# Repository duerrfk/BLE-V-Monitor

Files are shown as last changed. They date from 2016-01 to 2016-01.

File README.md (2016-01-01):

BLE-V-Monitor is a battery voltage monitor for vehicles (cars, motorbikes). It consists of an Arduino-based monitoring device and an Android app. The BLE-V-Monitor device is connected to the car battery to monitor the battery voltage and record voltage histories. The app queries the current voltage and voltage history via Bluetooth Low Energy (BLE) and displays them to the user.

The main features of BLE-V-Monitor are:

- Current voltage and battery charge status monitoring
- Recording of minutely, hourly, and daily voltage histories
- Bluetooth Low Energy (BLE) to transmit voltage samples to smartphones, tablets, Internet gateways, etc.
- Very low energy consumption
- Android app for displaying current voltage and voltage histories
- Open source hardware (CERN Open Hardware Licence v1.2) and software (Apache License 2.0)

The following images show the BLE-V-Monitor device and screenshots from the app.

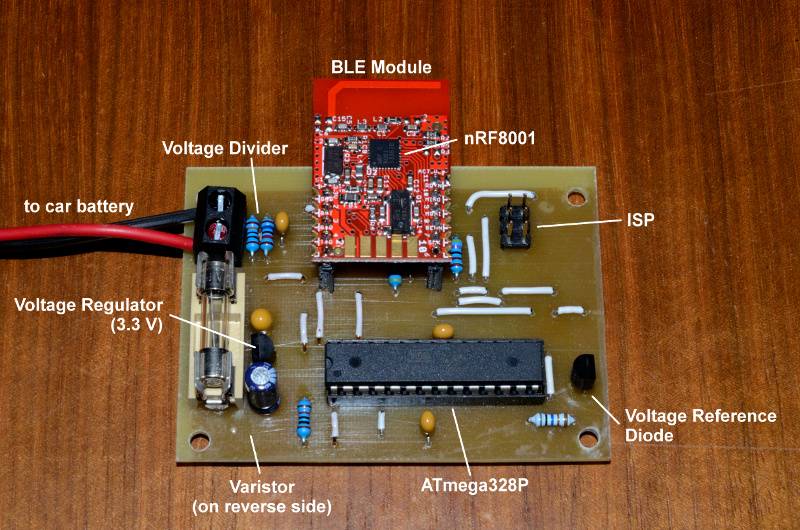
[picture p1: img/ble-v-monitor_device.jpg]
BLE-V-Monitoring device


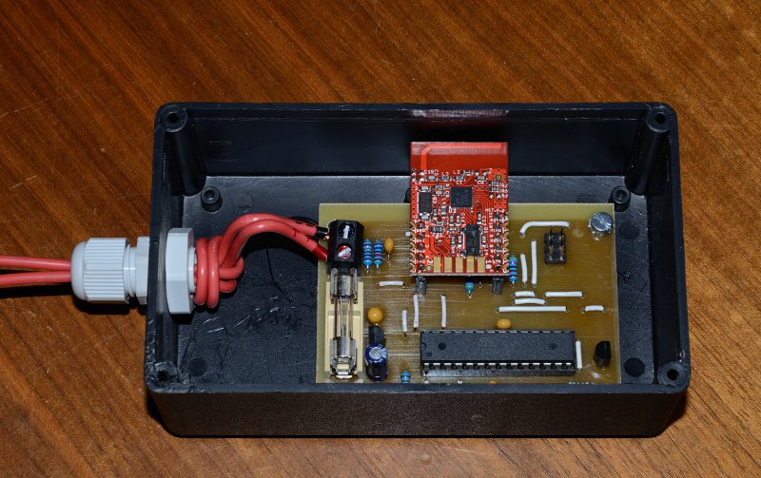
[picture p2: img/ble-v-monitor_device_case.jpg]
BLE-V-Monitoring device with case


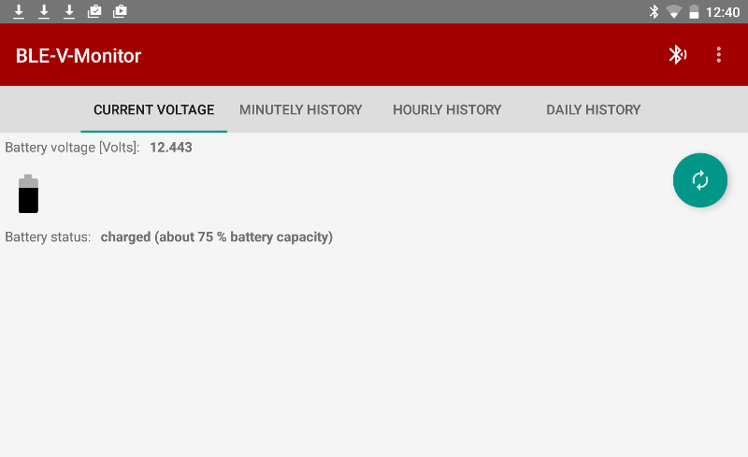
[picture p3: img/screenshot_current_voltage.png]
BLE-V-Monitor app: current voltage


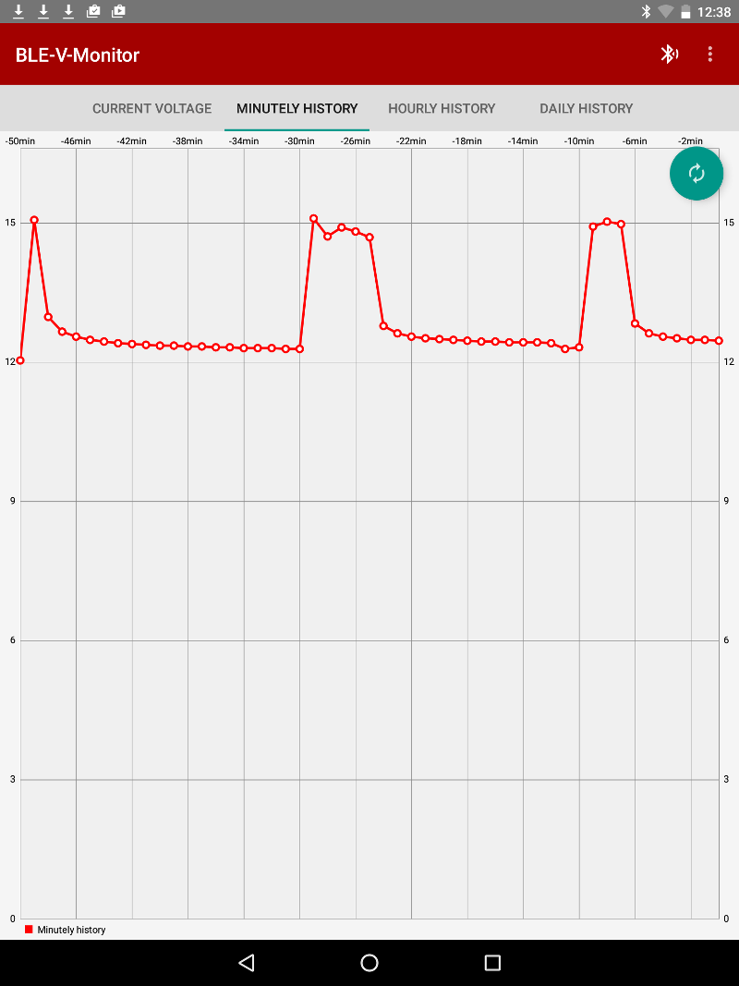
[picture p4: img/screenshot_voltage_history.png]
BLE-V-Monitor app: history


# Implementation

BLE-V-Monitor consists of two parts: 

* the BLE-V-Monitor device (PCB and Arduino software)
* a smartphone app for Android. 

You can find the following files here:

* Schematics and PCB layout (Eagle files) of the monitoring device: directory `eagle`.
* Arduino source code for monitor device: directory `src`.
* BLE service definition for nRF8001 used by monitoring device: directory `nRFgo_studio`. 
* Android app source code: directory `android`.

The BLE-V-Monitor device periodically samples the voltage of the battery, and the app uses Bluetooth Low Energy (BLE) to query the battery voltage when the smartphone is close to the car. Instead of using a smartphone, you could also implement a client for other devices, e.g., a Raspberry Pi with a Bluetooth USB stick (not included so far).

## Prerequisites

To compile the code for the monitoring device, you need the Arduino IDE (tested with version 1.6.5).

Moreover, you need the Arduino BLE SDK from Nordic Semiconductors available 
from GitHub:

https://github.com/NordicSemiconductor/ble-sdk-arduino

1. Download SDK: `git clone https://github.com/NordicSemiconductor/ble-sdk-arduino.git`
2. Start the Arduino IDE (tested with v1.6.5)
3. Import the library: select `Sketch/Import library/Add` library and 
   then choose folder `libraries/BLE` from the downloaded SDK.
4. Check the availability of the library. There should be an entry `BLE`
   in menu `Sketch/Import library`.

The BLE services of nRF8001 are configured by the freely available nRFgo 
Studio tool (Windows application) [4]. This tool generates a file 
(`services.h`), which is also included in the repository. Thus, you  
only need to install this tool if you want to modify the BLE service 
description for some reason.

The Android app requires at least Android 4.3 (API level 18). You need to install Android Studio to edit the project provided in this repository.

## BLE-V-Monitor Device

The BLE-V-Monitor device is based on the Arduino platform. It uses an ATmega 328P microcontroller and the BLE module MOD-nRF8001 from Olimex [2] featuring a Nordic Semiconductor nRF8001 BLE chip [1]. The ATmega is programmed via an in-system programmer (ISP) and interfaces with the BLE module through SPI. Due to small duty cycles, the current consumption can be below 100 microampere while no client is connected via BLE.

To measure voltage, we use the 10 bit analog/digital converter (ADC) of the ATmega. The voltage range that can be measured ranges from 0 to 18 V, thus, the resolution is 18 V / 1024 = 17.6 mV. Note that while the car is running, the car's alternator provides more than 12 V to charge the battery (about 15 V for my car as can be seen from the history screenshot). A voltage divider with large resistor values (to save energy) is used to divide the battery voltage. Since we use 2.5 V reference voltage, 18 V is mapped to 2.5 V by the voltage divider. A precise 2.5 V reference voltage is provided by the micropower voltage reference diode LM285-2.5, which is only powered on demand through a GPIO pin of the ATmega during sampling. Since the resistors of the voltage divider have large values to save energy, a 100 nF capacitor in parallel to the second resistor of the voltage divider provides a low impedance source to the ADC (this 100 nF capacitor is much larger than the 14 pF sampling capacitor of the ATmega).  

A 18 V varistor protects from transient voltage spikes above 18 V. Since varistors typically age whenever they shunt excessive voltage, a (slow) fuse limits the current to protect against a short circuit of the varistor.

A micropower voltage regulator (LP295x) provides 3.3 V to the ATmega and BLE module. The 100 mA that can be provided by this regulator are more than sufficient to power the ATmega and BLE module while being active, and a very low quiescent current of only 75 microampere ensures efficient operation with small duty cycles.

## Programming the Monitoring Device

The monitoring device is programmed via ISP. The 6 pin ISP6 connector has the usual layout:

    MISO <-- 1 2 --> VCC
     SCK <-- 3 4 --> MOSI
     RST <-- 5 6 --> GND

You can leave the BLE module connected while programming the ATmega (the 
4.7 k resistors shield the SPI pins of the nRF8001 during programming). However,
you should use a 3.3 V programmer since the maximum voltage of the nRF8001
is 3.6 V.

To preprare the ATmega328P, program the following fuses (note that "0" means 
that the fuse is programmed):

* CKSEL = 0010: use internal 8 MHz RC oscillator
* CKDIV8 = 1: 8 MHz system clock (do not divide the 8 MHz internal clock by 8)
* SPIEN = 0: enable serial programming
* BODLEVEL = 101: brown-out detection set to 2.7 V
* SUT = 00: lowest possible startup time (6 CK from power-down; since we use
  BOD, we do not need additional waiting time for the power source to come up)
    
Using avrdude, the command looks like this (note: under Linux you might need
to execute this command as root depending on your programmer):

    $ avrdude -c usbasp -p m328p -U lfuse:w:0xc2:m -U hfuse:w:0xd9:m -U efuse:w:0x05:m

Make sure to compile your code for the correct board. In the repository, 
you will find a suitable board definition for the Arduino IDE (see folder 
`board_definition`). Copy the directory `ble-v-monitor` into the folder 
`hardware` in your Arduino sketchbook. Then you should find and select the 
board  called `BLE-V-Monitor -- ATmega328P @ 8 MHz` under the menu item `Tools/Board`. 

Compiling generates a hex file that we need to program the ATmega. This hex 
file is a little bit hidden in the temporary build directory of the Arduino
IDE. If you use Linux  and Arduino IDE 1.6, have a look at the `/tmp` 
directory. After hitting the  compile button in the Arduino IDE, search for the
latest hex file called  `ble-v-monitor.cpp.hex` in a temporary directory named 
`/tmp/build...`. If you have found the hex file, you can write it using avrdude
(again, you might need root right):

    $ avrdude -p m328p -c usbasp -v -U flash:w:/tmp/build6535101126624677692.tmp/ble-v-monitor.cpp.hex

## BLE-V-Monitor App

The BLE-V-Monitor App is implemented for Android 4.3 and above. It consists of a tab view with a fragment to display the current voltage, and three more fragments to display minutely, hourly, and daily voltage histories, respectively.

The charge status of a lead–acid car battery can be quite easily derived from its voltage. We use the following voltage levels to estimate the charge status: 

- 100 % charged (fully charged): about 12.66 V
- 75 % charged (charged): about 12.35 V
- 50 % charged (weakly charged): about 12.10 V
- 25 % charged (discharged): about 11.95 V
- 0 % charged (over discharged): about 11.7 V

# Licensing

BLE-V-Monitor uses two licenses for open hardware and software, respectively:

* The software (source code) is licensed under the Apache License 2.0 [5]
* The hardware (schematic diagrams, circuit board layouts, hardware
  documentation) is licensed under the CERN Open Hardware Licence v1.2 [6]

# References

* [1] https://www.nordicsemi.com/eng/Products/Bluetooth-Smart-Bluetooth-low-energy/nRF8001 
* [2] https://www.olimex.com/Products/Modules/RF/MOD-nRF8001/
* [3] https://github.com/NordicSemiconductor/ble-sdk-arduino
* [4] https://www.nordicsemi.com/chi/node_176/2.4GHz-RF/nRFgo-Studio
* [5] http://www.apache.org/licenses/LICENSE-2.0
* [6] http://www.ohwr.org/attachments/2388/cern_ohl_v_1_2.txt

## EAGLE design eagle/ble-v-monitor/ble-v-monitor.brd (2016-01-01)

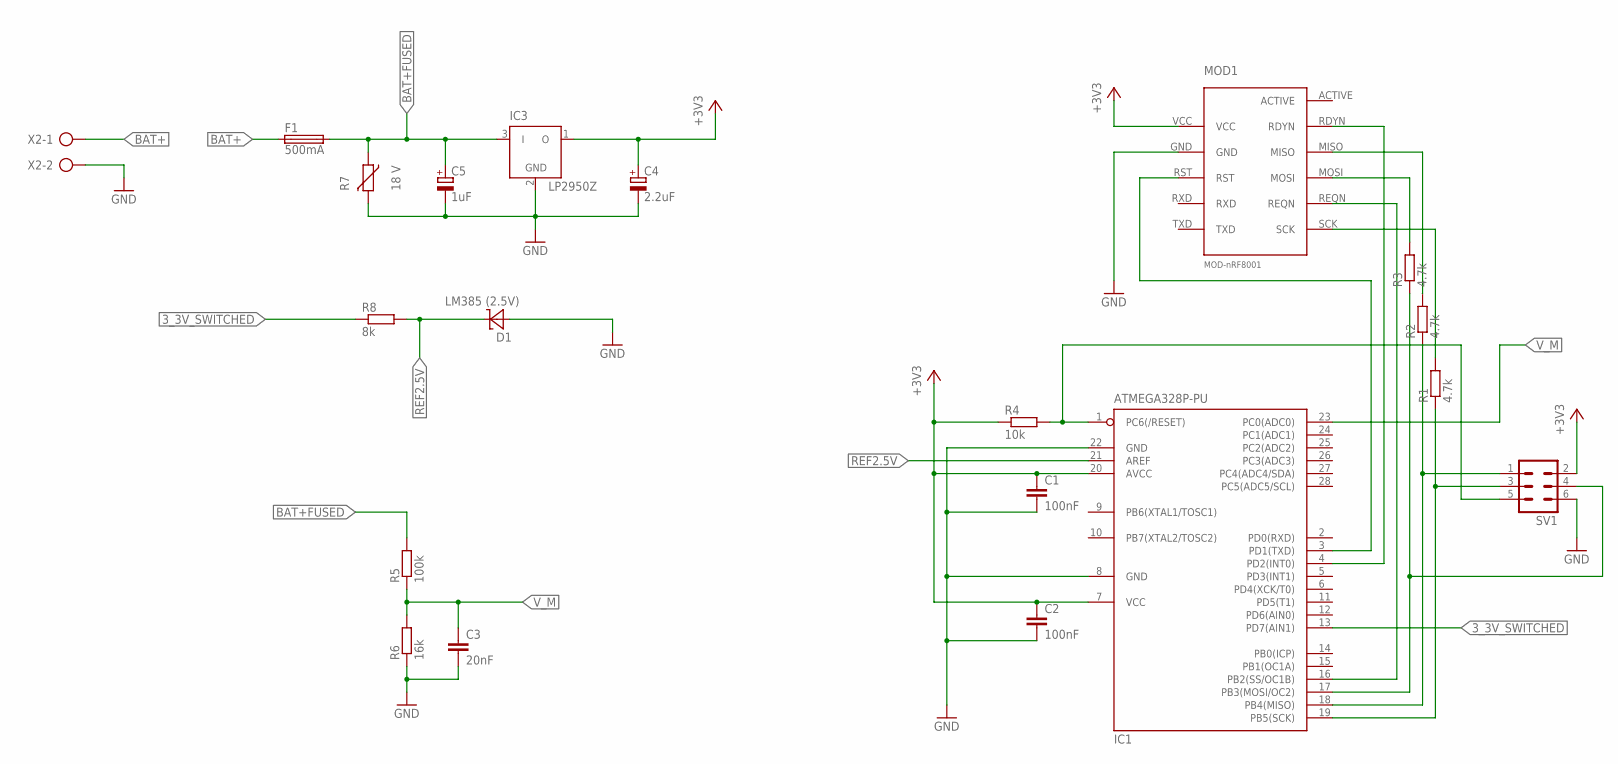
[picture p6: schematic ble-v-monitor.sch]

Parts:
C1, C2: 100nF; C050-024X044
C3: 20nF; C050-024X044
C4: 2.2uF; TT2D5
C5: 1uF; TT2D5
D1: LM385 (2.5V); TO-92
F1: 500mA; SH22,5
IC1: ATMEGA328P-PU; DIL28-3
IC3: LP2950Z; TO92
MOD1: MOD-NRF8001MOD-NRF8001; MOD-NRF8001
R1, R2, R3: 4.7k; 0207/7
R4: 10k; 0207/7
R5: 100k; 0207/7
R6: 16k; 0207/7
R7: 18 V; CT/CN0805
R8: 8k; 0207/7
SV1: MA03-2
X2: AK500/2

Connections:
3_3V_SWITCHED: IC1.13 (PD7(AIN1)), R8.1
+3V3: C1.1, C2.1, C4.+, IC1.7 (VCC), IC1.20 (AVCC), IC3.1 (O), MOD1.VCC, R4.1, SV1.2
BAT+: F1.1, X2.1
BAT+FUSED: C5.+, F1.2, IC3.3 (I), R5.2, R7.1
GND: C1.2, C2.2, C3.2, C4.-, C5.-, D1.+, IC1.8 (GND), IC1.22 (GND), IC3.2 (GND), MOD1.GND, R6.1, R7.2, SV1.6, X2.2
unnamed: MOD1.MOSI, R3.2
unnamed: IC1.1 (PC6(/RESET)), R4.2, SV1.5
unnamed: MOD1.SCK, R1.2
unnamed: IC1.19 (PB5(SCK)), R1.1, SV1.3
unnamed: MOD1.MISO, R2.2
unnamed: IC1.16 (PB2(SS/OC1B)), MOD1.REQN
unnamed: IC1.17 (PB3(MOSI/OC2)), R3.1, SV1.4
unnamed: IC1.3 (PD1(TXD)), MOD1.RST
unnamed: IC1.18 (PB4(MISO)), R2.1, SV1.1
unnamed: IC1.4 (PD2(INT0)), MOD1.RDYN
REF2.5V: D1.-, IC1.21 (AREF), R8.2
V_M: C3.1, IC1.23 (PC0(ADC0)), R5.1, R6.2

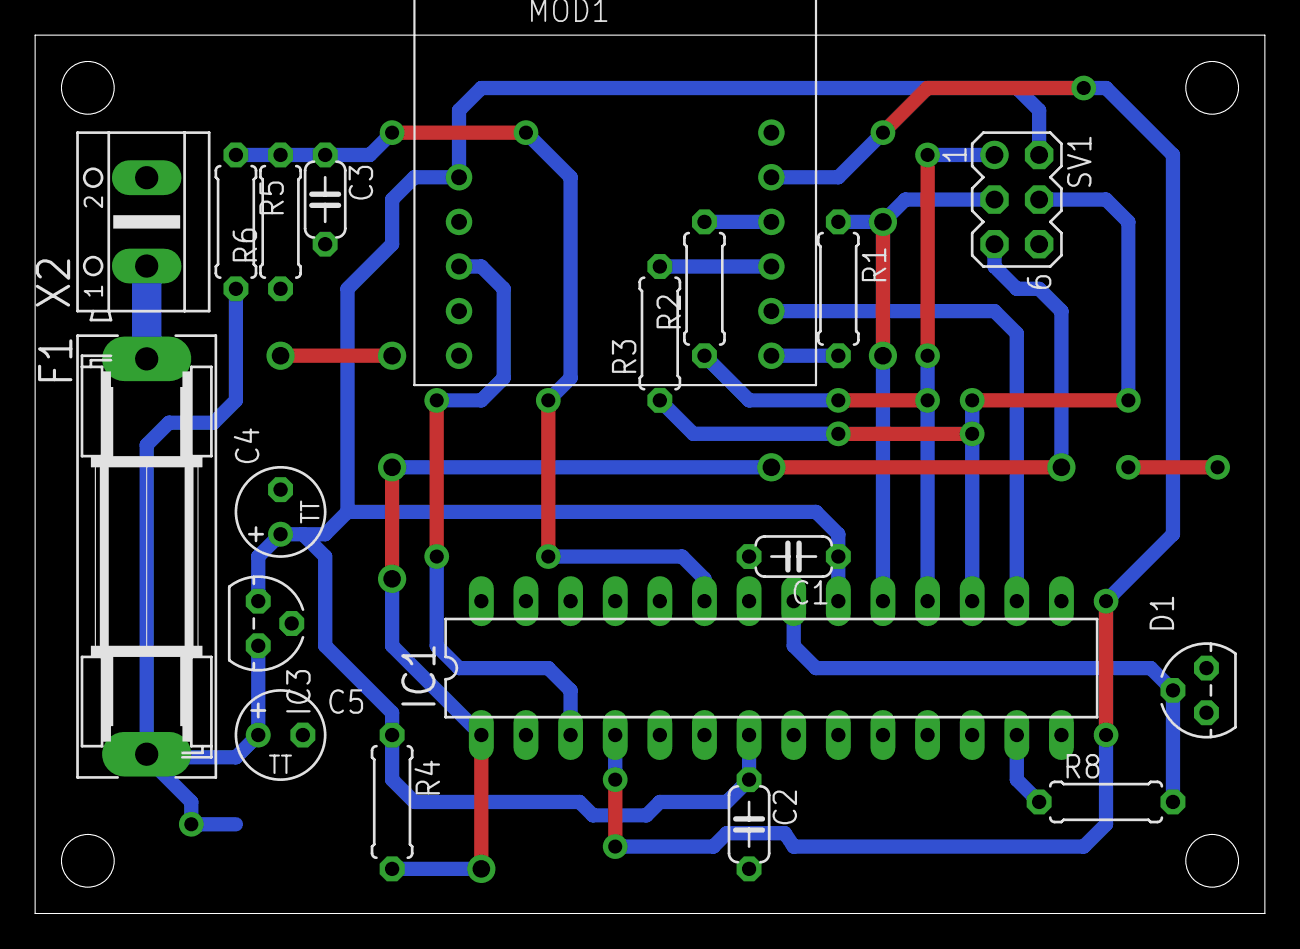
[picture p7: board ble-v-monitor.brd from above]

Board: 2 copper layers, 70.0 x 50.0 mm, 20 parts (1 on the bottom side), 17 nets.

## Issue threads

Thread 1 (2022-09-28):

Inversion between R5 and R6 in the voltage divider

Gis70, 2022-09-28:
Hello,

Thank you to this project that i'm using to monitor my cars and motorbike battery.

I discover that there is a inversion for R5 and R6 on you schematic.

R5 must be the 16Kohms resistor
R6 must be the 100KOhms resistor

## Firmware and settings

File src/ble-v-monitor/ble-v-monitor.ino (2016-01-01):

/**
 * This file is part of BLE-V-Monitor.
 * 
 * Copyright 2015 Frank Duerr
 *
 * Licensed under the Apache License, Version 2.0 (the "License");
 * you may not use this file except in compliance with the License.
 * You may obtain a copy of the License at
 * 
 * http://www.apache.org/licenses/LICENSE-2.0
 * 
 * Unless required by applicable law or agreed to in writing, software
 * distributed under the License is distributed on an "AS IS" BASIS,
 * WITHOUT WARRANTIES OR CONDITIONS OF ANY KIND, either express or implied.
 * See the License for the specific language governing permissions and
 * limitations under the License.
 */
 
// Need to include EEPROM.h here although it is not reference from this file
// (at least Arduino 1.5.8 IDE fails to include it automatically). 
#include <EEPROM.h>
#include <SPI.h>
#include <avr/wdt.h>
#include <avr/sleep.h>
#include <lib_aci.h>
#include <aci_setup.h>
#include "services.h"
#include "commands.h"

// Define your MCU. 
//#define ARDUINO_PRO_MICRO
#define ATMEGA328P

// Debug output over serial is not available with the
// BLE-V-Monitor board. However, if you use Arduino Pro Micro
// for developing, it might be handy.
//#define DEBUG

// For production system (BLE-V-Monitor board), enable 
// power-down mode to save energy (micro-amps while sleeping).
// DO NOT ENABLE THIS ON Arduino Pro Micro SINCE A SLEEPING
// ARDUINO CANNOT BE PROGRAMMED RELIABLY VIA SERIAL CONNECTION!!!
#define DO_SLEEP

// Disabling brown-out detecting while sleeping saves about 25 uA.
// Not all ATmega MCUs support this. ATmega328P used by the 
// BLE-V-Monitor board does. ATmega32U4 (e.g., used by Arduino 
// Pro Micro) doesn't.
#define DISABLE_BOD_WHILE_SLEEPING

//// Arduino pins connected to nRF8001.
#ifdef ARDUINO_PRO_MICRO
    // The following values are valid for Arduino Pro Micro. 
    #define PIN_MOSI 16
    #define PIN_MISO 14
    #define PIN_SCK 15
    // nRF8001 uses two "slave select" pins, one from Arduino (master) to nRF8001
    // (slave) called REQN, and one from slave to master called RDYN for signaling 
    // events from nRF8001 to Arduino. For RDYN select a pin with attached 
    // hardware interrupt to enable wake-up from sleep mode. 
    #define PIN_REQN 7
    #define PIN_RDYN 3  
    #define PIN_RST 4

    // Analog pin used for measuring voltage
    #define PIN_ADC_IN A0
    // Digital pin powering reference voltage
    #define PIN_POWER_ADC_REF_VOLTAGE 5
#endif

#ifdef ATMEGA328P
    // The following pins are valid for ATmega328P
    #define PIN_MOSI 11
    #define PIN_MISO 12
    #define PIN_SCK 13
    // nRF8001 uses two "slave select" pins, one from Arduino (master) to nRF8001
    // (slave) called REQN, and one from slave to master called RDYN for signaling 
    // events from nRF8001 to Arduino. For RDYN select a pin with attached 
    // hardware interrupt to enable wake-up from sleep mode. 
    #define PIN_REQN 10
    #define PIN_RDYN 2 
    #define PIN_RST 3

    // Analog pin used for measuring voltage
    #define PIN_ADC_IN A0
    // Digital pin powering reference voltage
    #define PIN_POWER_ADC_REF_VOLTAGE 7
#endif

// We use this interrupt to react to RDYN events. nRF8001 pulls
// RDYN low, when it has some data to send to the MCU.
#define RDYN_INTR_NO 0

// nRF8001 supports max. 3 MHz SPI clock frequency.
// Our Arduino runs at 8 MHz. By dividing by 4, we
// set the SPI clock frequency to 2 MHz.    
#define SPI_CLOCK_DIV SPI_CLOCK_DIV4

// BLE advertisement interval in 0.625 ms, min 0x0020 (20 ms), 
// max 0x4000 (10.240 s). 1600 -> 1 s
#define ADV_INTERVAL 1600

//// nRF8001 data structures
#ifdef SERVICES_PIPE_TYPE_MAPPING_CONTENT
services_pipe_type_mapping_t services_pipe_type_mapping[NUMBER_OF_PIPES] = 
    SERVICES_PIPE_TYPE_MAPPING_CONTENT;
#else
#define NUMBER_OF_PIPES 0
services_pipe_type_mapping_t *services_pipe_type_mapping = NULL;
#endif

// Store the setup for the nRF8001 in the flash of the AVR (PROGMEM) to save 
// on RAM
const hal_aci_data_t setup_msgs[NB_SETUP_MESSAGES] PROGMEM = 
    SETUP_MESSAGES_CONTENT;

// External reference voltage in volts
const float ref_voltage = 2.5;
// Voltage scale-up factor due to external voltage divider 
// (R1 = 100k, R2 = 16k). 
const float voltage_scaleup = (100.0+16.0)/16.0;
// Compensate for constant voltage offset (in volts).
// Requires calibration of device. Alternatively, we can
// compensate for errors on the client side (in the "app").
const float voltage_offset = 0.0;

// nRF8001 can only process one system command at a time.
// After sending a request, we need to wait for the response event
// before sending the next command. In order to simplify implementation,
// we queue pending commands in a command queue. Whenever a response
// event is received, the next command is taken out of the queue and sent
// to nRF8001. The command queue is implemented as a ring buffer.
#define CMD_QUEUE_SIZE 16
#define CMD_QUEUE_SIZE_MOD_MASK 0x0f 
enum commands cmd_queue[CMD_QUEUE_SIZE];
unsigned int cmd_queue_head = 0;
unsigned int cmd_queue_tail = 0;
unsigned int cmd_queue_free = CMD_QUEUE_SIZE;
boolean cmd_queue_pending = false;

struct aci_state_t aci_state;
hal_aci_evt_t  aci_data;
hal_aci_data_t aci_cmd;
boolean is_connected = false;

volatile boolean ble_ready = false;
volatile boolean timer_fired = false;

// This number indicates an invalid voltage
#define INVALID_VOLTAGE -1
// Voltage in micro-volts. 
int16_t voltage = INVALID_VOLTAGE;

// Timeout for receiving data credits in seconds.
#define CREDIT_TIMEOUT_THRESHOLD 180
unsigned int credit_timeout = 0;

// Timeout to take voltage samples in seconds.
// Should be an integral divisor of 60 (= one minute) to correctly
// calculate the minute timeout threshold below.
#define SAMPLE_TIMEOUT_THRESHOLD 10
unsigned int sample_timeout = 0;
const unsigned int minute_timeout_threshold = 60/SAMPLE_TIMEOUT_THRESHOLD;
unsigned int minute_timeout = 0;

unsigned int hour_timeout = 0;

unsigned int day_timeout = 0;

#define MAX_SEQ_NO 0xffffffffUL
#define HISTORY_RING_SIZE 128
#define HISTORY_RING_SIZE_MODMASK 0x7f

boolean is_voltage_notification_due = false;

boolean is_minutely_history_due = false;
uint32_t minutely_history_send_seqno = 0;
uint32_t minutely_history_head = 0;
int16_t minutely_history_ring[HISTORY_RING_SIZE];

boolean is_hourly_history_due = false;
uint32_t hourly_history_send_seqno = 0;
uint32_t hourly_history_head = 0;
int16_t hourly_history_ring[HISTORY_RING_SIZE];

boolean is_daily_history_due = false;
uint32_t daily_history_send_seqno = 0;
uint32_t daily_history_head = 0;
int16_t daily_history_ring[HISTORY_RING_SIZE];

boolean is_pipe_open_minutely_history = false;
boolean is_pipe_open_hourly_history = false;
boolean is_pipe_open_daily_history = false;

byte adcsra_save = ADCSRA;

/**
 * Called after a fatal error. 
 */
void die()
{  
    // Enable watchdog system reset mode to reboot system with next
    // watch dog event. 
    //WDTCSR |= _BV(WDE);
    
    // Go into endless loop.
    while (true) {
        #ifdef DEBUG
        Serial.println("DEAD");
        #endif
    }
}

/**
 * Enqueue a command into the command queue. 
 * 
 * @param command the command to be enqueued
 * 
 * @returns true if the command fits into the queue; false if
 *          there is no space in the queue anymore.
 */
boolean cmd_queue_enqueue(enum commands command)
{
    if (cmd_queue_free == 0)
        return false;

    cmd_queue[cmd_queue_head] = command;
    cmd_queue_head++;
    cmd_queue_head &= CMD_QUEUE_SIZE_MOD_MASK;
    cmd_queue_free--;
    
    // Try to send command
    cmd_queue_send_cmd();

    return true;
}

/**
 * If no other command is pending and there is at least
 * one queued command, send next command to nRF8001.
 */
void cmd_queue_send_cmd() 
{
    // Cannot send a command if either a command is pending 
    // or queue is empty
    if (cmd_queue_pending || cmd_queue_free == CMD_QUEUE_SIZE)
        return;
        
    enum commands cmd = cmd_queue[cmd_queue_tail];
    switch (cmd) {
    case cmd_start_advertising:
        // Start advertising in connectable mode.
        // First parameter defines the time how long to
        // advertise (0 = forever). Second parameter is advertisement 
        // interval in milli-seconds.
        #ifdef DEBUG
        Serial.println("ADVERTISE");
        #endif
        lib_aci_connect(0, ADV_INTERVAL);
        break;
    case cmd_change_timing:
        #ifdef DEBUG
        Serial.println("CHANGE TIMING");
        #endif
        lib_aci_change_timing_GAP_PPCP();
        break;
    case cmd_disconnect:
        #ifdef DEBUG
        Serial.println("DISCONNECT");
        #endif
        lib_aci_disconnect(&aci_state, ACI_REASON_TERMINATE);
        break;
    case cmd_set_data_voltage:
        #ifdef DEBUG
        Serial.println("SET DATA");
        #endif
        // Data is expected in Little Endian order. ATmega is LE.
        lib_aci_set_local_data(&aci_state, 
                               PIPE_BLE_V_MONITOR_BATTERY_VOLTAGE_SET,
                               (uint8_t *) &voltage, sizeof(int16_t));    
    }
    
    cmd_queue_pending = true;
    
    cmd_queue_tail++;
    cmd_queue_tail &= CMD_QUEUE_SIZE_MOD_MASK;
    
    cmd_queue_free++;
}

/**
 * Received response for pending command.
 */
void cmd_queue_response_recvd()
{
    cmd_queue_pending = false;

    // Can send next enqueued command now (if any is available)
    cmd_queue_send_cmd();
}
  
/**
 * This function is used by BLE library to signal failed assertions.
 */
void __ble_assert(const char *file, uint16_t line)
{
    while (true);
}

/**
 * ISR for RDYN low events
 */
void rdyn_isr()
{
    // This is a level interrupt that would fire again while the
    // signal is low. Thus, we need to detach the interrupt.
    detachInterrupt(RDYN_INTR_NO);
    ble_ready = true;  
}

/**
 * Watch dog interrupt. Will be fired every second.
 * 
 * The watch dog will keep runing even in power-down mode.
 * When it fires, it will wake-up the Arduino.
 */
ISR(WDT_vect)
{  
    timer_fired = true;
}

/**
 * Setup watch dog to trigger interrupts every 1 s.
 */
void start_watchdog()
{
    // WDTCSR: Watch Dog Control Status Register
    // WDIE: Watchdog Interrupt Enable
    // WDCE: Watchdog Change Enabled
    // WDE: Watchdog System Reset Enabled
    // WDRF: Watchdog Reset Flag
    /* Watch Dog Prescaler (WDP3-0)
    0         0      0        0             2K (2048) cycles      16 ms
    0         0      0        1             4K (4096) cycles      32 ms
    0         0      1        0             8K (8192) cycles      64 ms
    0         0      1        1            16K (16384) cycles     0.125 s
    0         1      0        0            32K (32768) cycles     0.25 s
    0         1      0        1            64K (65536) cycles     0.5 s
    0         1      1        0            128K (131072) cycles   1.0 s
    0         1      1        1            256K (262144) cycles   2.0 s
    1         0      0        0            512K (524288) cycles   4.0 s
    1         0      0        1            1024K (1048576) cycles 8.0 s
    */
    // Clear WDRF or it will overwrite cleared WDE.
    MCUSR &= ~_BV(WDRF);
    byte sreg_saved;
    sreg_saved = SREG;
    cli();
    // Watchdog modus:
    //  WDE, ~WDIE: system reset mode
    // ~WDE,  WDIE: interrupt mode
    //  WDE,  WDIE: interrupt mode; after first interrupt go to system reset 
    //              mode 
    // Changing timing and clearing WDE require a timed sequence:
    // Set WDCE bit; then change settings within 4 clock cycles.
    WDTCSR |= _BV(WDCE) | _BV(WDE);
    // Disable watchdog reset, enable interrupt mode, interval 1 s
    WDTCSR = _BV(WDP2) | _BV(WDP1) | _BV(WDIE);
    SREG = sreg_saved;
    wdt_reset();
}

/**
 * One-time setup.
 */
void setup()
{     
    wdt_disable();

    #ifdef DEBUG
    Serial.begin(9600);
    // Serial port of Arduino Pro Micro takes some time to be detected
    delay(5000);
    #endif

    // Configure pin providing reference voltage for ADC as output
    pinMode(PIN_POWER_ADC_REF_VOLTAGE, OUTPUT);
    // Switch it off to save energy while ADC is not used.
    digitalWrite(PIN_POWER_ADC_REF_VOLTAGE, LOW);
    
    // Use external voltage reference for ADC.
    analogReference(EXTERNAL);
    
    // Disable ADC (saves about 300 uA). ADC is re-enabled on demand 
    // when required.
    adcsra_save = ADCSRA;
    ADCSRA = 0;

    // Setup nRF800 using the definitions from services.h created by nRFgo 
    // Studio
    if (services_pipe_type_mapping != NULL) {
        aci_state.aci_setup_info.services_pipe_type_mapping = 
            &services_pipe_type_mapping[0];
    } else {
        aci_state.aci_setup_info.services_pipe_type_mapping = NULL;
    }
    aci_state.aci_setup_info.number_of_pipes = NUMBER_OF_PIPES;
    aci_state.aci_setup_info.setup_msgs = (hal_aci_data_t *) setup_msgs;
    aci_state.aci_setup_info.num_setup_msgs = NB_SETUP_MESSAGES;
    
    // Pin mapping from nRF8001 to Arduino. Not connected pins are defined as 
    // UNUSED.
    aci_state.aci_pins.board_name = BOARD_DEFAULT;
    aci_state.aci_pins.reqn_pin = PIN_REQN;
    aci_state.aci_pins.rdyn_pin = PIN_RDYN;
    aci_state.aci_pins.mosi_pin = PIN_MOSI;
    aci_state.aci_pins.miso_pin = PIN_MISO;
    aci_state.aci_pins.sck_pin = PIN_SCK;
    aci_state.aci_pins.reset_pin = PIN_RST;
    aci_state.aci_pins.active_pin = UNUSED;
    aci_state.aci_pins.optional_chip_sel_pin = UNUSED;
    
    aci_state.aci_pins.spi_clock_divider = SPI_CLOCK_DIV;
    
    // We implement our own interrupt handling to better control
    // when we spend time for nRF8001 event processing and when for 
    // other things like sensor readings. Moreover, this will help
    // us to implement a correct sleep/wake-up procedure that
    // is not missing events.
    // Therefore, we turn off interrupts here and poll nRF8001
    // in the event loop whenever we think it's suitable.
    aci_state.aci_pins.interface_is_interrupt = false;
    aci_state.aci_pins.interrupt_number = 0;
    
    // Reset nRF8001. 
    // Set second parameter to true for debug output.
    lib_aci_init(&aci_state, false);
    
    // Install interrupt for RDYN line of nRF8001 for event handling.
    // We use a level-interrupt that can also fire in sleep mode to
    // wake up the Arduino when an event is received.
    attachInterrupt(RDYN_INTR_NO, rdyn_isr, LOW);

    start_watchdog();
}
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
void loop()
{                 
    if (ble_ready) {
        // Process all pending ACI events from nRF8001.
        aci_loop();
        ble_ready = false;
        // nRF8001 will cause an interrupt when more events are available
        attachInterrupt(RDYN_INTR_NO, rdyn_isr, LOW);
    }

    if (timer_fired) {
        #ifdef DEBUG
        Serial.println("TIMER EVENT"); // DEBUG
        #endif
        
        // "If no credit event is received within 180 seconds after issuing
        // a data command, then the application controller should issue the 
        // disconnect command to recover from this error condition."
        credit_timeout++;
        boolean credit_pending = aci_state.data_credit_available < 
                                 aci_state.data_credit_total;                         
        if (is_connected && credit_pending && 
            credit_timeout >= CREDIT_TIMEOUT_THRESHOLD)
            cmd_queue_enqueue(cmd_disconnect);

        sample_timeout++;
        if (sample_timeout > SAMPLE_TIMEOUT_THRESHOLD) {
            #ifdef DEBUG
            Serial.println("SAMPLE TIMEOUT");
            #endif
            take_sample();
            sample_timeout = 0;
            // Update voltage characteristic.
            if (lib_aci_is_pipe_available(&aci_state, 
                                      PIPE_BLE_V_MONITOR_BATTERY_VOLTAGE_SET)) {
                cmd_queue_enqueue(cmd_set_data_voltage);
            }
            // Send notification if there is a subscriber
            is_voltage_notification_due = true;
            send_pending_data();

            minute_timeout++;
            if (minute_timeout >= minute_timeout_threshold) {
                // Completed another minute
                #ifdef DEBUG
                Serial.println("MINUTE TIMEOUT");
                #endif
                minutely_history_ring[minutely_history_head&HISTORY_RING_SIZE_MODMASK] = voltage;
                minutely_history_head++;
                minute_timeout = 0;
                
                // Hour timeout is measured in minutes
                hour_timeout++;
                if (hour_timeout >= 60) {
                    // Completed another hour
                    #ifdef DEBUG
                    Serial.println("HOUR TIMEOUT");
                    #endif
                    hourly_history_ring[hourly_history_head&HISTORY_RING_SIZE_MODMASK] = voltage;
                    hourly_history_head++;
                    hour_timeout = 0;
                    
                    // Day timeout is measured in hours
                    day_timeout++;
                    if (day_timeout >= 24) {
                        #ifdef DEBUG
                        Serial.println("DAY TIMEOUT");
                        #endif
                        daily_history_ring[daily_history_head&HISTORY_RING_SIZE_MODMASK] = voltage;
                        daily_history_head++;
                        day_timeout = 0;
                    }
                }
            }
        }
       
        timer_fired = false;
    }

    #ifdef DO_SLEEP
    do_sleep();
    #endif
}
